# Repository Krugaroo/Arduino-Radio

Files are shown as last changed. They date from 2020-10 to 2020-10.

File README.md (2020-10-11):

# Arduino Radio
 A simple solar powered FM radio project
 
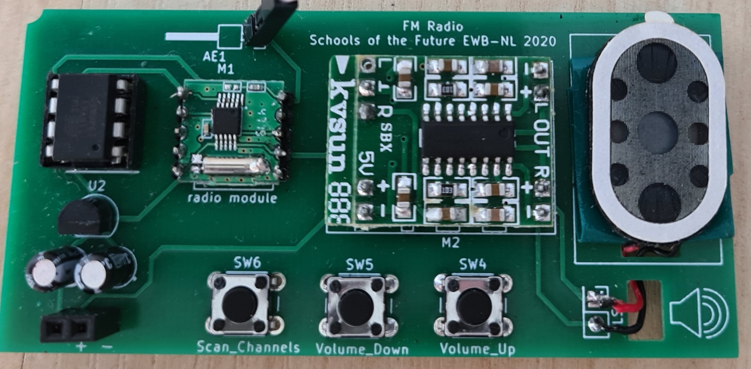
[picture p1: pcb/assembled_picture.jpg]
Image of Radio
 
 
 *Note: The software included in this project is complete and can be used to flash onto an Arduino directly. The final project is intended to be on a custom PCB with an AtTiny-85 microcontroller.
 The PCB design is on its first revision, and requires some workaround. I will finish the PCB and add a proper readme in the future.*
 
 This project is a simple solar power radio that was to be used in a volunteering project via Engineers without Borders to teach and engage children with science and engineering.
 It was intended to be a fun and useful project for schools kids on our yearly trip to Mozambique to teach Engineering [https://www.ewbnl.org/schools-of-the-future/]. However due to Covid-19 the execution is currently postphoned.
 
 I have made the PCB design and Arduino software available freely in the hope that it might still be of use.
 
 The project uses a simple module (RDA5807) that can be bought cheaply and controlled over I2C using a microcontroller (i.e Arduino). The audio is amplified with an amplifier (PAM8403). I have included a BOM list for reference.
 The total cost at single units is less than 10 Euro.
 
 # How it works
 The radio can search for channels by keeping the scan button pressed. Once the desired channel is found let go of the button.
 The volume can be increased/decreased by pressing the volume up and down buttons
 Once a channel and volume is selected it will be stored in the EEPROM so it does not need to be tuned again when power is restored.

 # Tips
 1. The PCB design is nearly complete, but was put on hold. As such I plan to still work on it. Let me know if there is interest to do so. The PCB is workable but requires a workaround, because of the switch to the AtTiny 85
 2. When soldering the RDA5807 it is a lot easier to do it upside down so the crystal and small chip is facing down, this exposes the pads much better.
 3. If you have trouble getting it to work make sure the crystal on the RDA5807 is not shorted. This is quite easily to do accidentally when soldering.
 4. For the antenna any piece of wire will do, it will probably also work okayish without one.
 
 If you run into any problems please post an issue in Github!

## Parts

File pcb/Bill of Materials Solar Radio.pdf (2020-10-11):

Bill of Materials Solar Radio

Description | Quantity | Cost/Unit | Total Cost | Link | Alt Link
3V LDO Regulator | 1 | 0.38 | 0.38 | https://www.tme.eu/nl/en/details/mcp1700-3002eto/ldo-unregulated-voltage-regulators/microchip-technology/mcp1700-3002e-to/ | https://nl.mouser.com/ProductDetail/Microchip-Technology/MCP1700-3002E-TO
32 Ohm 0.5W Spealer | 1 | 0.8 | 0.8 | https://nl.aliexpress.com/item/32954867366.html
1uF Electrolytic Capacitor | 2 | 0.05 | 0.1 | https://www.tme.eu/nl/en/details/ce-1_50sp/85degc-tht-electrolytic-capacitors/sr-passives/
Microswitch Tact | 3 | 0.23 | 0.69 | https://www.tme.eu/nl/en/details/skhhaka010/microswitches-tact/alps/
Radio RDA5807 | 1 | 0.34 | 0.34 | https://nl.aliexpress.com/item/32349154695.html?spm=a2g0o.cart.0.0.555c3c003RQVOM&mp=1
ATtiny85-20PU 8bit MCU | 1 | 1.48 | 1.48 | https://www.tme.eu/en/details/attiny85-20pu/8-bit-avr-family/microchip-atmel/
Audio Amplifier PAM8403 | 1 | 0.2 | 0.2 | https://nl.aliexpress.com/item/32515881989.html
6V 330mA solar Panel | 1 | 4.27 | 4.27 | https://www.aliexpress.com/item/32877897718.html
PCB | 1 | 1 | 1
Total Cost | | | 9.26

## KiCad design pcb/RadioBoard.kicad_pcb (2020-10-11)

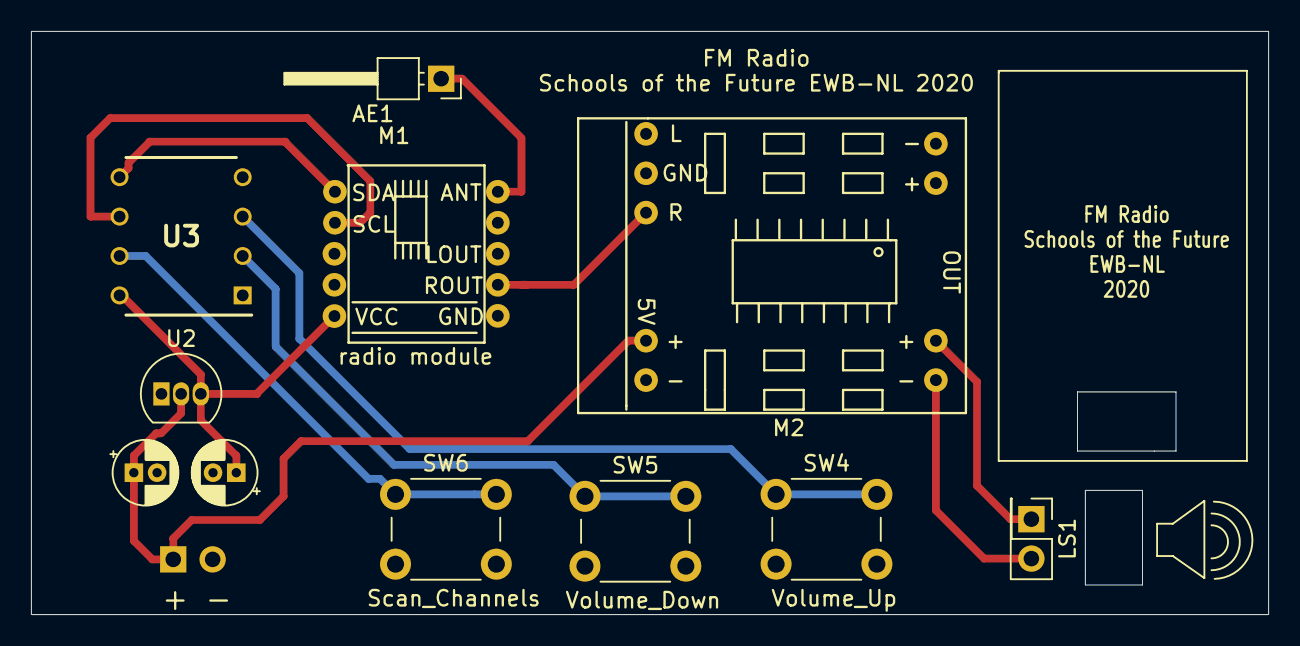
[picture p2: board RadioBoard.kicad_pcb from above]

Board: 2 copper layers, 79.8 x 37.6 mm, 12 parts (1 on the bottom side), 12 nets.

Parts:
AE1: Antenna; PinHeader_1x01_P2.54mm_Horizontal
C4, C5: 1 uF; CP_Radial_D4.0mm_P1.50mm
J1: Power Input; PinHeader_1x02_P2.54mm_Vertical
LS1: Speaker; PinHeader_2x01_P2.54mm_Vertical
M1: module_radio_RDA5807M
M2: module_audioamp_PAM8403
SW4: Volume_Up; SW_PUSH_6mm
SW5: Volume_Down; SW_PUSH_6mm
SW6: Scan_Channels; SW_PUSH_6mm
U2: MCP1700-3002E_TO92; TO-92_Inline
U3: ATtiny13V-10PU; DIP794W56P254L959H533Q8N

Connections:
GND: C4.2, C5.2, J1.2, M1.10, M2.2, M2.5, SW4.2, SW5.2, SW6.2, U2.1, U3.4
unnamed: AE1.1, M1.6
unnamed: C5.1, M1.5, U2.3, U3.8
unnamed: LS1.1, M2.8
unnamed: LS1.2, M2.9
unnamed: M1.1, U3.5
unnamed: M1.2, U3.6
unnamed: M1.9, M2.3
unnamed: SW4.1, U3.3
unnamed: SW5.1, U3.2
unnamed: SW6.1, U3.7
OUTPUT_SOUND: C4.1, J1.1, M2.4, U2.2

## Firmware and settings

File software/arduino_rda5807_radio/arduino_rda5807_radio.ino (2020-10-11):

/*
  Arduino Radio based on the RDA5807 module
  
  Copyright (c) 2020 Michael Kruger
  
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
  THE SOFTWARE IS PROVIDED "AS IS", WITHOUT WARRANTY OF ANY KIND, EXPRESS OR
  IMPLIED, INCLUDING BUT NOT LIMITED TO THE WARRANTIES OF MERCHANTABILITY,
  FITNESS FOR A PARTICULAR PURPOSE AND NONINFRINGEMENT. IN NO EVENT SHALL THE
  AUTHORS OR COPYRIGHT HOLDERS BE LIABLE FOR ANY CLAIM, DAMAGES OR OTHER
  LIABILITY, WHETHER IN AN ACTION OF CONTRACT, TORT OR OTHERWISE, ARISING FROM,
  OUT OF OR IN CONNECTION WITH THE SOFTWARE OR THE USE OR OTHER DEALINGS IN THE
  SOFTWARE.
*/

// Define this if building for the AtTiny-85
#define BUILD_FOR_ATTINY85

// Build for AtTiny-85:
// To program this use the following settings:
// https://create.arduino.cc/projecthub/arjun/programming-attiny85-with-arduino-uno-afb829

#ifdef BUILD_FOR_ATTINY85
// i2c library for AtTiny85, install with Sketch->Include Library->Manage Libraries and search for USIWire and click on install
#include <USIWire.h>
#else
// Build for Arduino's with native I2C support:
#include <Wire.h>
#endif

#include <EEPROM.h>

#define BTN_VOL_UP 4
#define BTN_SCAN 3
#define DEFAULT_CHANNEL 100


#define ADDRESS_INDEX 0x11
#define ADDRESS_SEQ  0x10

#define REG_CONTROL 0x02
#define REG_CHANNEL 0x03
#define REG_AFC 0x04
#define REG_VOLUME 0x05
#define REG_READ_CHANNEL 0x0A

// Reg Control
#define AUDIO_OUTPUT_EN 0x8000
#define AUDIO_DMUTE_EN  0x4000
#define AUDIO_MONO_EN   0x2000
#define AUDIO_BASS_EN   0x1000

#define AUDIO_SEEKUP_EN 0x0200
#define AUDIO_SEEK_EN   0x0100
#define AUDIO_SEEK_MODE 0x0080
#define AUDIO_RDS_EN    0x0008
#define AUDIO_NEW_METH  0x0004
#define AUDIO_RESET     0x0002
#define AUDIO_ENABLE    0x0001

#define CHANNEL_SEL      0xFFC0
#define TUNE             0x0010
#define BAND_WORLD       0x000C
#define CHANNEL_25KHZ    0x0003
#define CHANNEL_50KHZ    0x0002
#define CHANNEL_200KHZ   0x0001
#define CHANNEL_100KHZ   0x0000

void writeReg(byte reg, uint16_t value) {
  Wire.beginTransmission(ADDRESS_INDEX);
  Wire.write(reg);
  Wire.write(value >> 8);
  Wire.write(value & 0xFF);
  Wire.endTransmission();
}

uint16_t readReg(byte reg) {
  Wire.beginTransmission(ADDRESS_INDEX);
  Wire.write(REG_VOLUME);                  
  Wire.endTransmission(0);          
  Wire.requestFrom(ADDRESS_INDEX,2,1); 
  return(256*Wire.read() + Wire.read());
}

uint16_t getFreq() {      
  Wire.requestFrom(ADDRESS_SEQ,2,1); 
  return(256*Wire.read() + Wire.read());
}

uint8_t volume = 2;
uint8_t channel = 0;

uint8_t channel_changed = 0;
uint8_t unsaved_change = 0;

uint8_t volume_up_press_dur = 0;
uint8_t scan_press_dur = 0;

uint16_t save_ticks = 0;

void setup() {
  // put your setup code here, to run once:
  pinMode(BTN_VOL_UP, INPUT);
  digitalWrite(BTN_VOL_UP, HIGH);
  pinMode(BTN_SCAN, INPUT);
  digitalWrite(BTN_SCAN, HIGH);
  
  Wire.begin();
  
  uint8_t saved_channel = EEPROM.read(0);
  uint8_t saved_volume= EEPROM.read(1);

  if(saved_volume != 255) {
    volume = saved_volume & 0xF;
  }

  if(saved_channel != 255) {
    channel = saved_channel;
  }
  
  writeReg(REG_CONTROL, AUDIO_OUTPUT_EN | AUDIO_DMUTE_EN | AUDIO_RESET | AUDIO_ENABLE);
  writeReg(REG_AFC, 0x0A00);
  delay(1000);
  writeReg(REG_CONTROL, AUDIO_OUTPUT_EN | AUDIO_DMUTE_EN | AUDIO_ENABLE);
  uint16_t current_reg = (readReg(REG_VOLUME)&0xFFF0);
  writeReg(REG_VOLUME, current_reg | volume);
  writeReg(REG_CHANNEL, (channel << 6) | TUNE | CHANNEL_100KHZ);
  
}

void loop() {
  // put your main code here, to run repeatedly:

  delay(50);

  // Scan
  if(digitalRead(BTN_SCAN) == LOW) {
    scan_press_dur++;
    if(scan_press_dur > 30) {
      scan_press_dur = 0;
      channel++;
      if(channel > 210) {
        channel = 0;
      }
      writeReg(REG_CONTROL, AUDIO_OUTPUT_EN | AUDIO_SEEK_EN | AUDIO_SEEKUP_EN | AUDIO_DMUTE_EN | AUDIO_ENABLE);
      channel_changed = 1;
      
    }
  } else if(channel_changed == 1) {
    // Only save after channel was kept.
    unsaved_change = 1;
    channel_changed = 0;
  }
  
  // Volume UP
  if (digitalRead(BTN_VOL_UP) == LOW) {
    volume_up_press_dur++;
  } else if(digitalRead(BTN_VOL_UP) == HIGH && volume_up_press_dur > 0) {
    volume_up_press_dur = 0;
    
    volume ++;
    if (volume > 10) {
      volume = 0;
    }
    uint16_t current_reg = (readReg(REG_VOLUME)&0xFFF0);
    writeReg(REG_VOLUME, current_reg | volume);

    unsaved_change = 1;
  }

  if(unsaved_change != 0) {
    save_ticks++;

    if(save_ticks > 200) {
      uint16_t channel_reg = getFreq();
      channel = (channel_reg) & 0xFF;
      EEPROM.update(0, channel);
      EEPROM.update(1, volume);
      unsaved_change = 0;
    }
  }

}

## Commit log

2020-10-11 Initial Commit
    Initial Commit of the Radio Arduino project
    [RadioBoard.kicad_pcb, RadioBoard.sch]
2020-10-11 Added Picture
    Added a picture of the assembled radio
